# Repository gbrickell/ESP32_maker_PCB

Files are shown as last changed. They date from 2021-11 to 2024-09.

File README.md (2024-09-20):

# ESP32 Maker PCB v3.0
## Documentation and example code for usage exploration of:
 - basic electronic functions
 - LCD, OLED and LED displays
 - servo, stepper and drive motor control
 - SPIFFS and SD card reader storage
 - various sensors, and
 - web server set ups to control Kit connected items from a browser

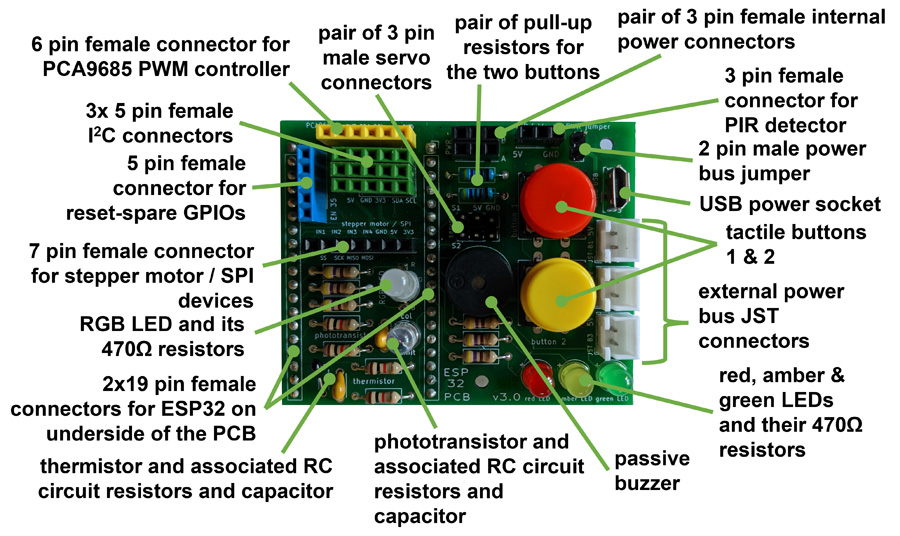
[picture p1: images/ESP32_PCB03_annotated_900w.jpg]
  &nbsp; &nbsp; 

  A robust permanent assembly, that connects to the GPIO pins of a 38 pin ESP32 module, can be created by soldering a set of components into a custom Printed Circuit Board (PCB v3.0). The module design, as shown above, includes a number of on-board devices that can be controlled by the ESP32 (e.g. buzzer, LEDs, etc.), but also allows a wide range of further components to be connected to the PCB enabling more ESP32 controlled systems to be explored.

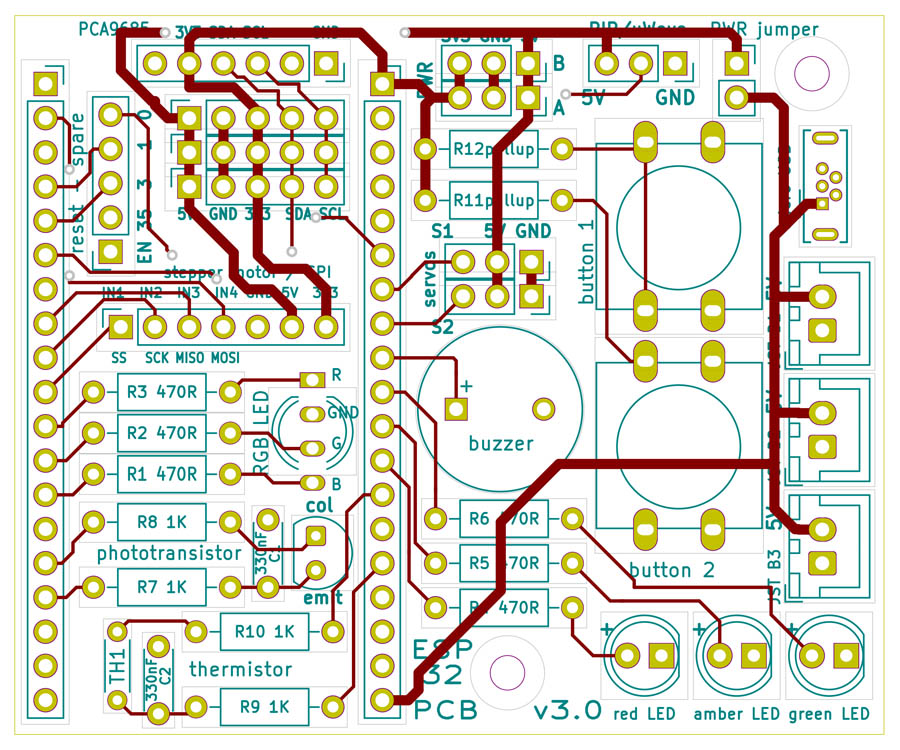
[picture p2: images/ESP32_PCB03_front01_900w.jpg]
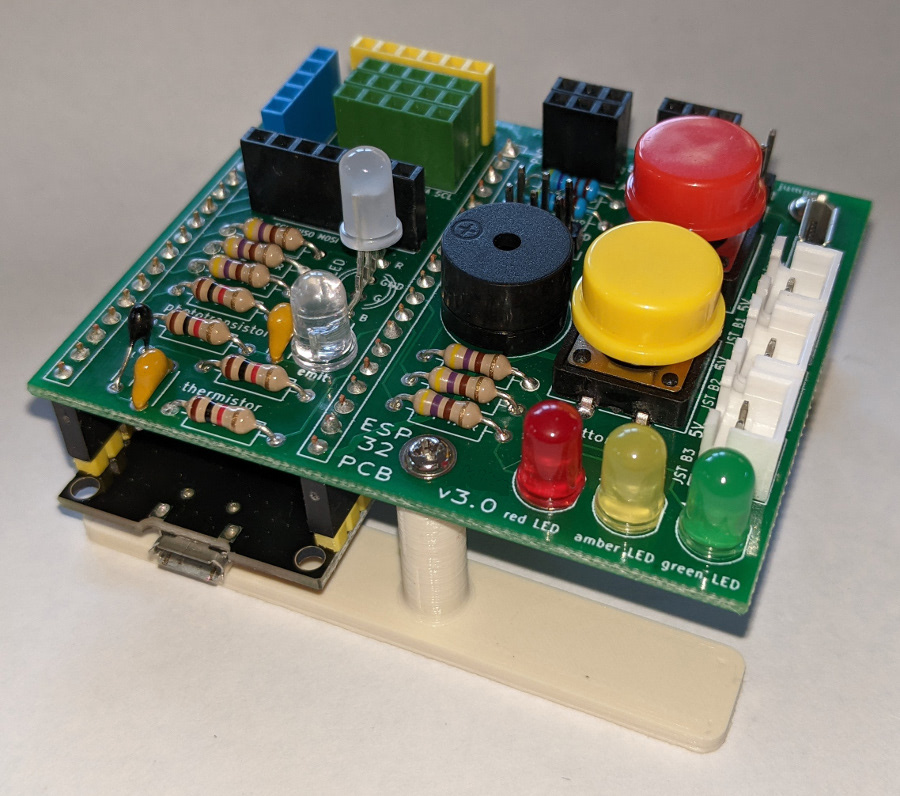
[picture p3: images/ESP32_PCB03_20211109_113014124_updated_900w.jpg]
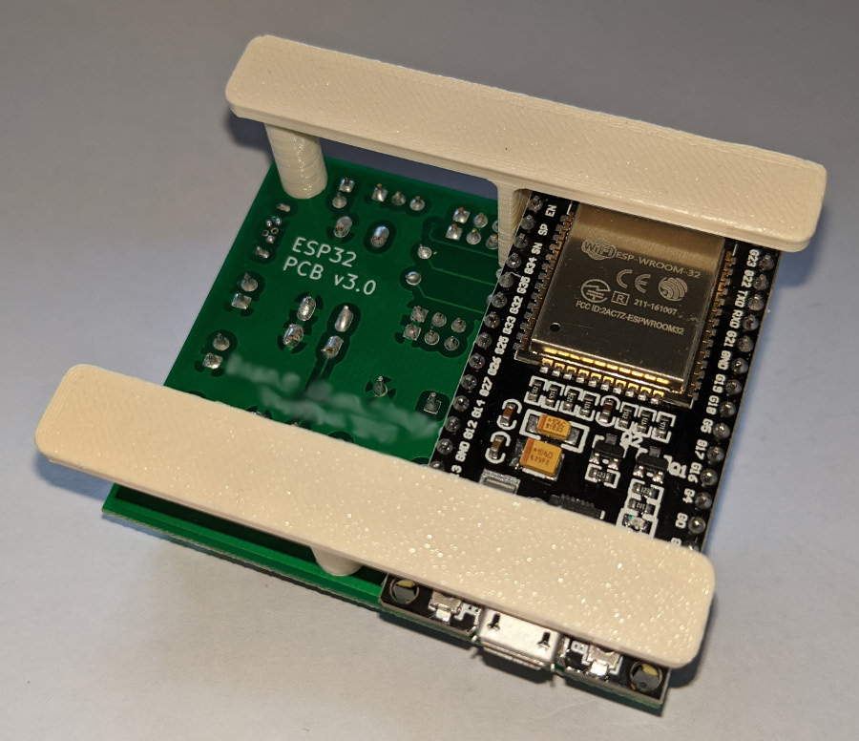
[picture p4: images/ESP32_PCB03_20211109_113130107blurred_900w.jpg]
 &nbsp; &nbsp;  &nbsp; &nbsp;  

Full details about the project are published at <a href="https://onlinedevices.org.uk/ESP32+Maker+PCB" target="_blank" >this link</a> and the designs for a small number of associated custom 3D printed components can be downloaded from the Prusa web site <a href="https://www.prusaprinters.org/prints/87023-esp32-maker-pcb-stands" target="_blank" >here</a>.

## Custom PCB design

The custom PCB (now at v3.0) was designed using KiCAD and the layout has been defined to provide all the components needed to build a fully populated module.

Gerber files for the PCB design can be downloaded from the PCB_design_files folder.

## Example code

All the example code was developed using the Arduino IDE and various standard/readily available libraries. Of particular note is the use of the TFT_eSPI library for use with SPI displays, where a Customs_Setup folder is provided which should be added to the display library folder along with a User_Setup_Select.h file, also added to the library folder, which provides the custom path references.

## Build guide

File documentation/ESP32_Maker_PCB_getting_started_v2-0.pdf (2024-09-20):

The aim of this evolving project is to provide access to an expanding library of example code to allow a digital maker to explore and control many different components and devices.
This is achieved, as shown on the right, by using a custom PCB with the other components listed above, to create an assembly that can connect to a 38-pin ESP32 microcontroller module with the
pair of custom 3D printed ‘stands’ used
to create a stable arrangement.

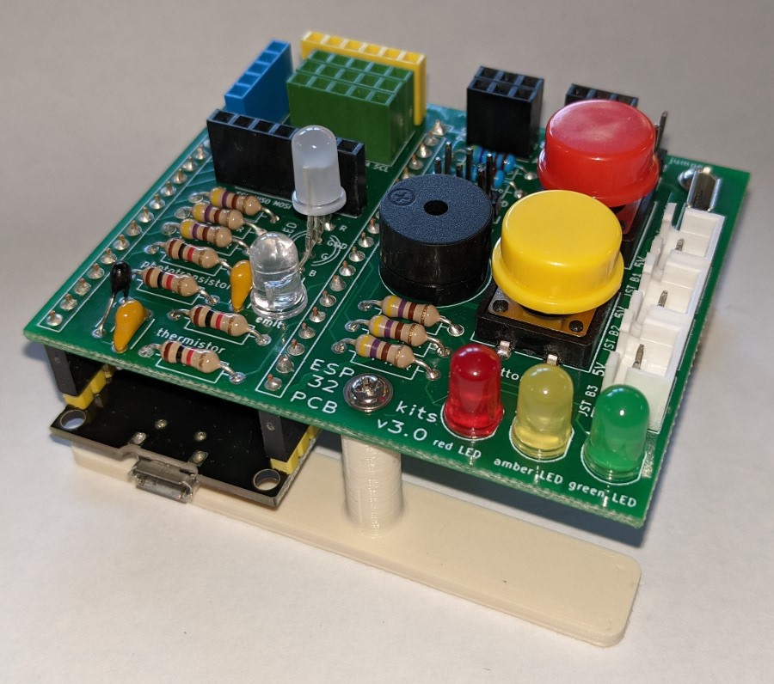
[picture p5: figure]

©Ê2024ÊGeoffÊBrickell | versionÊ2.0ÊÊÊÊÊÊÊÊÊÊÊÊÊÊÊÊÊÊÊÊÊÊSeptemberÊ2024

### Required component summary:

1x printed circuit board (PCB) | 4x 1kΩ resistors
1x red LED | 2x 330nF capacitors
1x amber LED | 1x Thermistor 10kΩ NTC
1x green LED | 1x Phototransistor
1x RGB LED | 2x tactile buttons
6x 470Ω resistors | 2x button coloured caps
1x passive buzzer | 2x 4.7kΩ (pull-up) resistors
1x 1row x 6P female yellow header | 3x 1row x 5P female green headers
1x 1row x 5P female blue header | 3x 1row x 3P female black headers
1x 1row x 7P female black header | 2x 1row x 19P female black header
2x 1row x 3P male black header | 1x USB type B micro socket
1x 3D printed PCB centre leg ‘stand’ + 1x 6mm M2 self-tap screw | 1x 1row x 2P male black header + jumper
1x 3D printed PCB side leg ‘stand’ + 1x 6mm M2 self-tap screw | 3x JST sockets + plugs with leads

# Getting started with your ESP32 Maker PCB

©Ê2024ÊGeoffÊBrickell | versionÊ2.0ÊÊÊÊÊÊÊÊÊÊÊÊÊÊÊÊÊÊÊÊÊÊÊSeptemberÊ2024

It should be noted that only low voltage DC power supplies, e.g., 5V rechargeable battery banks/PSUs, or 4xAA battery packs, should be connected to the PCB’s separate ‘power bus’.
In addition the ’power bus’ should only be interconnected to the PCB’s main 5V power line, using the ‘jumper’ connection point, if the supply to the ‘power bus’ is at a safe maximum 5V level for the ESP32.
For each of the projects/methods described in the main documentation you should ensure that the ESP32 is not powered when connecting the PCB to the ESP32 or devices are connected to the PCB.

Assembling a complete PCB is a significant soldering task for which some experience at soldering is needed. However with some adult supervision, the soldering could be carried out by ages 10 and above. In addition, with an adult carrying out the soldering of components onto the PCB, ages as young as 7 should be able to run the projects, although at this early age not all the physics and maths associated with the projects may be fully understood.

To get started: ESP32_Maker_PCB_v4_support_material.zip, that contains all the software and documentation, can be downloaded from: ÊÊhttps://onlinedevices.org.uk/dl1919ÊÊ
- where the last set of characters are lower case DL1919
The ESP32_maker_PCB_usage_documentation_v3-0.pdf file in the .ZIP provides assembly and detailed usage instructions, and a separate ESP32_code folder contains example software. All the software is C/C++ for use with the Arduino IDE with individual code ‘sketches’ available to control the components directly fitted to the Maker PCB as well as a wide variety of additional components that can be connected to the PCB.
To manage code changes and to upload individual code ‘sketches’ to the ESP32 microcontroller, a separate computer is needed to run the Arduino IDE which can be installed on a variety of machines (Windows PC, Mac, Raspberry Pi, etc).

### Software & documentation:

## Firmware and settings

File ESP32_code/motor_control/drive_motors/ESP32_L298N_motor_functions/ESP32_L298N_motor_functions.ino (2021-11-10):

// ESP32_L298N_drive_1motor_test.ino - basic L298N drive motor test with the ESP32 maker kit
// just powers one motor and uses PWM for speed control
// 

//  code developed and compiled using the Arduino IDE v1.8.13
//  ESP32 Dev Module set as the Board in the IDE - using board version 2.0.0
//   even though the board is probably the NodeMCU-32S i.e. 38 pin ESP32
//  Flash Size: 4MB
//  Partition Scheme set to: Default 4MB with spiffs (1.2 MB App / 1.5MB SPIFFS)
//   lots of other Board settings! but none experimented with

// powered by a 5V battery bank or 4xAA battry holder connected to the micro UB/JST power bus 
// and the L298N also connected to the JST sockets
// four GPIO's (for 2 motors) used for the IN1-IN4 pins on the black 7P header on the PCB

// button 2 used to trigger the motor test cycle
//  which is pulled-up with a physical resistor
int btn_pin = 34; // GPIO pin on one side of the bottom button (2)

// Motor A
int in1 = 5;   // IN1
int in2 = 18;  // IN2
int enA = 32;  // using the servo1 connection

// Motor B
int in3 = 19;  // IN3
int in4 = 23;  // IN4
int enB = 33;  // using the servo2 connection

// Setting PWM properties
const int freq = 1000;
const int pwmChannelA = 0;
const int pwmChannelB = 1;
const int resolution = 8; // 8 bit resolution means duty cycle range is 0-254
int dutyA = 0; // PWM value from 0-255
int dutyB = 0; // PWM value from 0-255

void setup() {

  Serial.begin(115200);
  delay(1000); // short delay to set up the monitor

  Serial.println("program starting ..... ");

  // pins 1, 3, 5, 14, and 15 are set HIGH on boot - so set them LOW unless/until they are needed
  pinMode(1, OUTPUT);
  pinMode(3, OUTPUT);
  pinMode(5, OUTPUT);
  pinMode(14, OUTPUT);
  pinMode(15, OUTPUT);
  digitalWrite(1, LOW);
  digitalWrite(3, LOW);
  digitalWrite(5, LOW);
  digitalWrite(14, LOW);
  digitalWrite(15, LOW); 

  pinMode(btn_pin, INPUT); // make the button connected GPIO pin an INPUT

  // sets the pins as outputs:
  pinMode(enA, OUTPUT);
  pinMode(in1, OUTPUT);
  pinMode(in2, OUTPUT);
  pinMode(in3, OUTPUT);
  pinMode(in4, OUTPUT);
  pinMode(enB, OUTPUT);
  
  // configure LED PWM functionalitites
  ledcSetup(pwmChannelA, freq, resolution);
  ledcSetup(pwmChannelB, freq, resolution);
  // attach the PWM channels to the GPIOs to be controlled
  ledcAttachPin(enA, pwmChannelA);
  ledcAttachPin(enB, pwmChannelB);
 
  Serial.println("motor loop test running");
  Serial.println("press button 2 to run the test");

}

void loop() {

  if (digitalRead(btn_pin) == LOW) {  // check if button has been pressed

    // if here button has been pressed so do the motor test cycle
    // Move Motors A + B forward at maximum speed
    Serial.println("Moving Motors A + B Forward");
    forward(255, 255);
    delay(3000);
    // Stop the motors
    Serial.println("Motor stopped");
    stop(1);
    delay(1000);

    // Move Motors A + B backwards at maximum speed
    Serial.println("Moving Motors A + B  Backwards");
    backward(255, 255);
    delay(3000);
    // Stop the motors
    Serial.println("Motor stopped");
    stop(1);
    delay(1000);

    // turn left at maximum speed
    Serial.println("Turning left");
    turnLeft(1000, 255);
    delay(1000);

    // turn right at maximum speed
    Serial.println("Turning right");
    turnRight(1000, 255);
    delay(1000);

    // spin left at maximum speed
    Serial.println("Spinning left");
    spinLeft(1000, 255, 255);
    delay(1000);

    // spin right at maximum speed
    Serial.println("Spinning right");
    spinRight(1000, 255, 255);
    delay(1000);

    Serial.print("button 2 reset to ");
    Serial.println(digitalRead(btn_pin));
    Serial.println("press button 2 to re-run the test");
    
  }
    
}

void forward (int dutyCycleA, int dutyCycleB) {
    // separate duty cycles are set so that each motor can be fine tuned if they vary in performance

    // set enA with the PWM dutycycle
    ledcWrite(pwmChannelA, dutyCycleA); // Send PWM signal to motor A (left)
    // set in1 on and in2 off i.e. HIGH - LOW for forward motion
    digitalWrite(in1, HIGH);
    digitalWrite(in2, LOW);

    // set enB with the PWM dutycycle   
    ledcWrite(pwmChannelB, dutyCycleB); // Send PWM signal to motor B (right)
    // set in3 on and in4 off i.e. HIGH - LOW for forward motion
    digitalWrite(in3, HIGH);
    digitalWrite(in4, LOW);

    Serial.print(" forward: dutyCycleA - ");
    Serial.println(dutyCycleA);
    Serial.print(" forward: dutyCycleB - ");
    Serial.println(dutyCycleB);
}
 
void backward(int dutyCycleA, int dutyCycleB) {
    // separate duty cycles are set so that each motor can be fine tuned if they vary in performance

    // set enA with the PWM dutycycle
    ledcWrite(pwmChannelA, dutyCycleA); // Send PWM signal to motor A (left)
    // set in1 off and in2 on i.e. LOW - HIGH for backward motion
    digitalWrite(in1, LOW);
    digitalWrite(in2, HIGH);

    // set enB with the PWM dutycycle
    ledcWrite(pwmChannelB, dutyCycleB); // Send PWM signal to motor B (right)
    // set in3 off and in4 on i.e. LOW - HIGH for backward motion
    digitalWrite(in3, LOW);
    digitalWrite(in4, HIGH);

    Serial.print(" backward: dutyCycleA - ");
    Serial.println(dutyCycleA);
    Serial.print(" backward: dutyCycleB - ");
    Serial.println(dutyCycleB);
}

void turnLeft(int turn_time, int dutyCycleB) {
    // set enB with the PWM dutycycle
    ledcWrite(pwmChannelB, dutyCycleB); // Send PWM signal to motor B (right)
    // set in3 on and in4 off - i.e. HIGH - LOW for right motor forward motion
    digitalWrite(in3, HIGH);
    digitalWrite(in4, LOW);
    // wait for turn_time ms
    delay(turn_time);
    stop(1);

    Serial.print(" turn left: dutyCycleB - ");
    Serial.println(dutyCycleB);
    Serial.print(" turn left: turn time - ");
    Serial.println(turn_time);
}
 
void turnRight(int turn_time, int dutyCycleA) {
    // set enA with the PWM dutycycle
    ledcWrite(pwmChannelA, dutyCycleA); // Send PWM signal to motor A (left)
    // set in1 on and in2 off i.e. HIGH - LOW for left motor forward motion
    digitalWrite(in1, HIGH);
    digitalWrite(in2, LOW);
    // wait for turn_time ms
    delay(turn_time);
    stop(1);

    Serial.print(" turn right: dutyCycleA - ");
    Serial.println(dutyCycleA);
    Serial.print(" turn left: turn time - ");
    Serial.println(turn_time);
}

 
void spinLeft(int spin_time, int dutyCycleA, int dutyCycleB) {
    // set enA with the PWM dutycycle
    ledcWrite(pwmChannelA, dutyCycleA); // Send PWM signal to motor A (left)
    // set in1 off and in2 on i.e. LOW - HIGH for left motor backward motion
    digitalWrite(in1, LOW);
    digitalWrite(in2, HIGH);

    // set enB with the PWM dutycycle
    ledcWrite(pwmChannelB, dutyCycleB); // Send PWM signal to motor B (right)
    // set in3 on and in4 off i.e. HIGH - LOW for right motor forward motion
    digitalWrite(in3, HIGH);
    digitalWrite(in4, LOW);
    // wait for spin_time ms
    delay(spin_time);
    stop(1);

    Serial.print(" spin left: dutyCycleA - ");
    Serial.println(dutyCycleA);
    Serial.print(" spin left: dutyCycleB - ");
    Serial.println(dutyCycleB);
    Serial.print(" spin left: spin time - ");
    Serial.println(spin_time);
}
 
void spinRight(int spin_time, int dutyCycleA, int dutyCycleB) {
    // set enA with the PWM dutycycle
    ledcWrite(pwmChannelA, dutyCycleA); // Send PWM signal to motor A (left)
    // set in1 on and in2 off i.e. HIGH - LOW for left motor forward motion
    digitalWrite(in1, HIGH);
    digitalWrite(in2, LOW);

    // set enB with the PWM dutycycle
    ledcWrite(pwmChannelB, dutyCycleB); // Send PWM signal to motor B (right)
    // set in3 off and in4 on i.e. LOW - HIGH for right motor backward motion
    digitalWrite(in3, LOW);
    digitalWrite(in4, HIGH);
    // wait for spin_time ms
    delay(spin_time);
    stop(1);

    Serial.print(" spin right: dutyCycleA - ");
    Serial.println(dutyCycleA);
    Serial.print(" spin right: dutyCycleB - ");
    Serial.println(dutyCycleB);
    Serial.print(" spin right: spin time - ");
    Serial.println(spin_time);
}
 
void stop(int stop_mode) {

    if (stop_mode == 1) {
        // full braking mode
        // set enA with 100% PWM dutycycle
        ledcWrite(pwmChannelA, 255); // Send PWM signal to motor A (left)
        // set in1 off and in2 off i.e. LOW- LOW for no motion
        digitalWrite(in1, LOW);
        digitalWrite(in2, LOW);

        // set enB with 100% PWM dutycycle
        ledcWrite(pwmChannelB, 255); // Send PWM signal to motor B (right)
        // set in3 off and in4 off i.e. LOW- LOW for no motion
        digitalWrite(in3, LOW);
        digitalWrite(in4, LOW);

    } 
    
    else if (stop_mode == 0) {
        // coasting stop mode
        // set enA with 0% PWM dutycycle
        ledcWrite(pwmChannelA, 0); // Send PWM signal to motor A (left)
        // set in1 off and in2 off i.e. LOW- LOW for no motion
        digitalWrite(in1, LOW);
        digitalWrite(in2, LOW);

        // set enB with 0% PWM dutycycle
        ledcWrite(pwmChannelB, 0); // Send PWM signal to motor B (right)
        // set in3 off and in4 off i.e. LOW- LOW for no motion
        digitalWrite(in3, LOW);
        digitalWrite(in4, LOW);
    }
    delay(10); // short pause for the stop to come into effect

    Serial.print(" stop: mode - ");
    Serial.println(stop_mode);
}

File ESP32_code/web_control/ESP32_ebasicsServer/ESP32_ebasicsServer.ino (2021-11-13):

// ESP32_ebasicsServer.ino  web server to operate some of the ESP32 Maker Kit's electronics

//  code developed and compiled using the Arduino IDE v1.8.13
//  ESP32 Dev Module set as the Board in the IDE - using board version 1.0.4
//   even though the board is probably the NodeMCU-32S i.e. 38 pin ESP32
//  Flash Size: 4MB
//  Partition Scheme set to: Default 4MB with spiffs (1.2 MB App / 1.5MB SPIFFS)
//   lots of other Board settings! but none experimented with

#include "WiFi.h"
#include "WebServer.h"
#include <WiFiClient.h>
#include <ESPmDNS.h>         // Include the mDNS library

const char* ssid = "xxxxxxxxx";    // use local SSID here
const char* password = "yyyyyyyy"; // use password for local SSID here

// hostname as a char variable
const char* namehost = "38pinESP32";

WebServer server(80);  //instantiate the web server at port 80 (http port#)

// *******************************************
// set the various LED and buzzer variables
// *******************************************
const int redled = 14;    // red LED on the Maker Kit PCB
const int amberled = 27; // amber LED on the Maker Kit PCB
const int greenled = 26;  // green LED on the Maker Kit PCB
const int buzzpin = 25;   // buzzer on the Maker Kit PCB
const int redPin = 17;     // RGB red
const int greenPin = 16;   // RGB green
const int bluePin = 4;     // RGB blue

// *********************
// web page variables
// *********************
String header_content;
String page_content = "";   // initialised global variable for web page content

// *****************************
// ** initial set up function **
// *****************************
void setup(void) {

  Serial.begin(115200);
  delay(1500); // short delay to set up the monitor
  Serial.println("program starting ..... ");

  // pins 1, 3, 5, 14, and 15 are set HIGH on boot - so set them LOW unless/until they are needed
  pinMode(1, OUTPUT);
  pinMode(3, OUTPUT);
  pinMode(5, OUTPUT);
  pinMode(14, OUTPUT);
  pinMode(15, OUTPUT);
  digitalWrite(1, LOW);
  digitalWrite(3, LOW);
  digitalWrite(5, LOW);
  digitalWrite(14, LOW);
  digitalWrite(15, LOW); 
  Serial.println("pin defaults reset..... ");

  // *************************************
  // prepare the RGB and RAG LEDs & buzzer
  // *************************************
  pinMode(redPin, OUTPUT);
  pinMode(greenPin, OUTPUT);
  pinMode(bluePin, OUTPUT);
  pinMode(redled, OUTPUT);
  digitalWrite(redled, 1);  // set ON to signify start of program
  pinMode(amberled, OUTPUT);
  pinMode(greenled, OUTPUT);
  pinMode(buzzpin, OUTPUT);

  WiFi.mode(WIFI_STA);
  WiFi.begin(ssid, password);
  Serial.println("");

  // Wait for connection using the WiFi.waitForConnectResult() function
  if (WiFi.waitForConnectResult() != WL_CONNECTED) {
    Serial.println("WiFi Connect Failed! Rebooting...");
    delay(1000);
    ESP.restart();
  }
  
  Serial.println("");
  Serial.print("IP address: ");
  delay(500);
  Serial.println(WiFi.localIP());
  Serial.print("MAC address: ");
  delay(500);
  Serial.println(WiFi.macAddress());

  if (MDNS.begin("esp32")) {
    Serial.println("MDNS responder started");
  }

  WiFi.setHostname(namehost);
  delay(1500);
  Serial.print("updated hostname: ");
  Serial.println(WiFi.getHostname());

  digitalWrite(redled, 0);
  digitalWrite(greenled, 1);  // signifies WiFi connected

  // ************************************************************************
  // interrupt 'handlers' triggered by various Web server requests:
  //  each specific URL that is detected by the web server invokes a 
  //  designated function that does something and then refreshes the web page
  // ************************************************************************
  // ** do this if web root i.e. / is requested
  server.on("/", handle_root);

  // ****** main selection actions ******
  // ** do this if /RAGleds is requested
  server.on("/RAGleds", handle_RAG);
  // ** do this if /RGBleds is requested
  server.on("/RGBleds", handle_RGB);
  // ** do this if /buzz is requested
  server.on("/buzz", handle_buzz);
  // ** do this if /sysinfo is requested
  server.on("/sysinfo", handle_sysinfo);

  // ****** sub selection parameter update actions ******
  // ******  do these if RAG ON/OFFs are selected  ******
  server.on("/RAGredON", handle_RAGredON);
  server.on("/RAGredOFF", handle_RAGredOFF);
  server.on("/RAGamberON", handle_RAGamberON);
  server.on("/RAGamberOFF", handle_RAGamberOFF);
  server.on("/RAGgreenON", handle_RAGgreenON);
  server.on("/RAGgreenOFF", handle_RAGgreenOFF);

  // ******  do these if RGB ON/OFFs are selected  ******
  server.on("/RGBredON", handle_RGBredON);
  server.on("/RGBredOFF", handle_RGBredOFF);
  server.on("/RGBgreenON", handle_RGBgreenON);
  server.on("/RGBgreenOFF", handle_RGBgreenOFF);
  server.on("/RGBblueON", handle_RGBblueON);
  server.on("/RGBblueOFF", handle_RGBblueOFF);

  // ******  do these if buzzer 'tunes' are selected  ******
  server.on("/buzz01", handle_buzz01);
  server.on("/buzz02", handle_buzz02);
  server.on("/buzz03", handle_buzz03);

  server.onNotFound(handleNotFound);

  server.begin();
  Serial.println("HTTP server started");

  // ** do a one-time population of the common header HTML used in all web pages
  header_content = HTMLheader();
  
}

void loop(void) {
  server.handleClient();
}

// *****************************************
// *******  RGB LED colour set *************
// *****************************************
void RGB_color(String colour)
{
    if (colour == "red") {
        digitalWrite(redPin, HIGH);
        digitalWrite(greenPin, LOW);
        digitalWrite(bluePin, LOW);
    } else if (colour == "green") {
        digitalWrite(redPin, LOW);
        digitalWrite(greenPin, HIGH);
        digitalWrite(bluePin, LOW);
    } else if (colour == "blue") {
        digitalWrite(redPin, LOW);
        digitalWrite(greenPin, LOW);
        digitalWrite(bluePin, HIGH);
    } else if (colour == "off") {
        digitalWrite(redPin, LOW);
        digitalWrite(greenPin, LOW);
        digitalWrite(bluePin, LOW);
    } else {
        Serial.println("unrecognised RGB setting");
    }

}
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
